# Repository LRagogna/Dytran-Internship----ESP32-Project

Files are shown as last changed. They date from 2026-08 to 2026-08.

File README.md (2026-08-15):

# Portable ESP32 Time-Study System

An end-to-end engineering project that turns production instructions into portable, operator-controlled time studies. The system combines a battery-powered ESP32 terminal, custom electronics and enclosure design, embedded firmware, and a Windows desktop application for creating, recording, reviewing, and exporting study data.

## Demo

[▶ Watch the ESP32 Time-Study System demo video](Pictures/esp32_time_study_demo.mp4)

The demo shows the completed handheld prototype running the on-device study workflow, including study selection, step navigation, and operator-controlled timing.

## Final prototype

The completed system packages the ESP32, display, physical controls, battery hardware, and interface electronics into a portable 3D-printed enclosure.

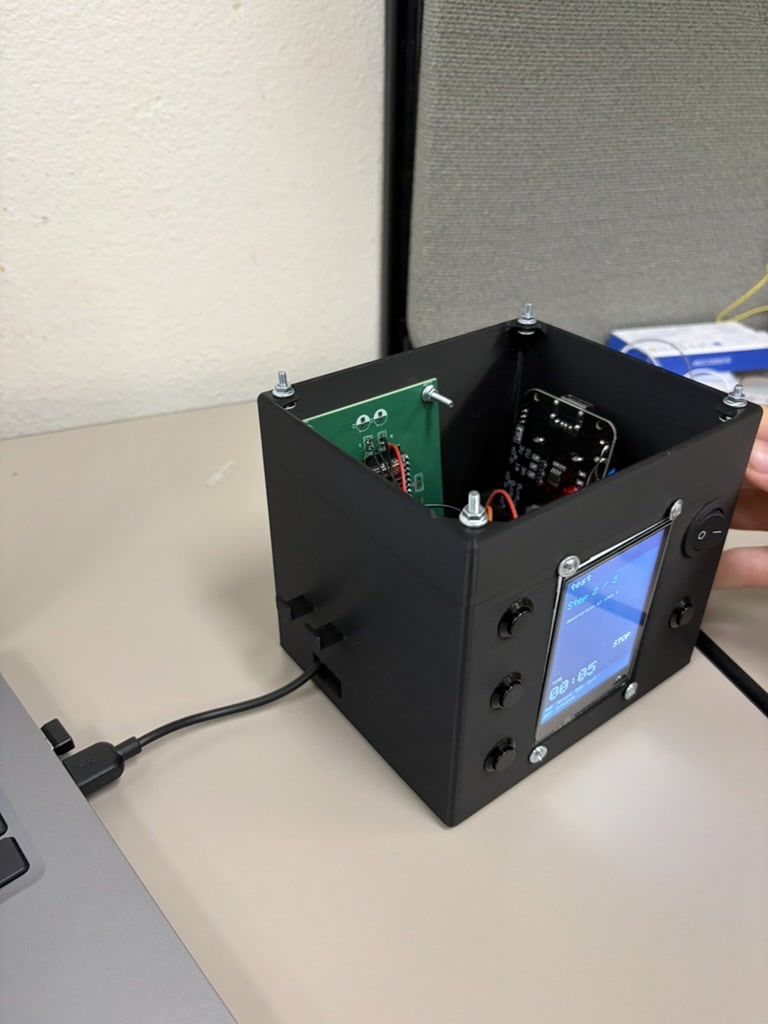
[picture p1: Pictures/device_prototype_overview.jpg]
Completed ESP32 time-study prototype


### On-device study selection

Stored studies can be selected directly from the handheld device before beginning a timing session.

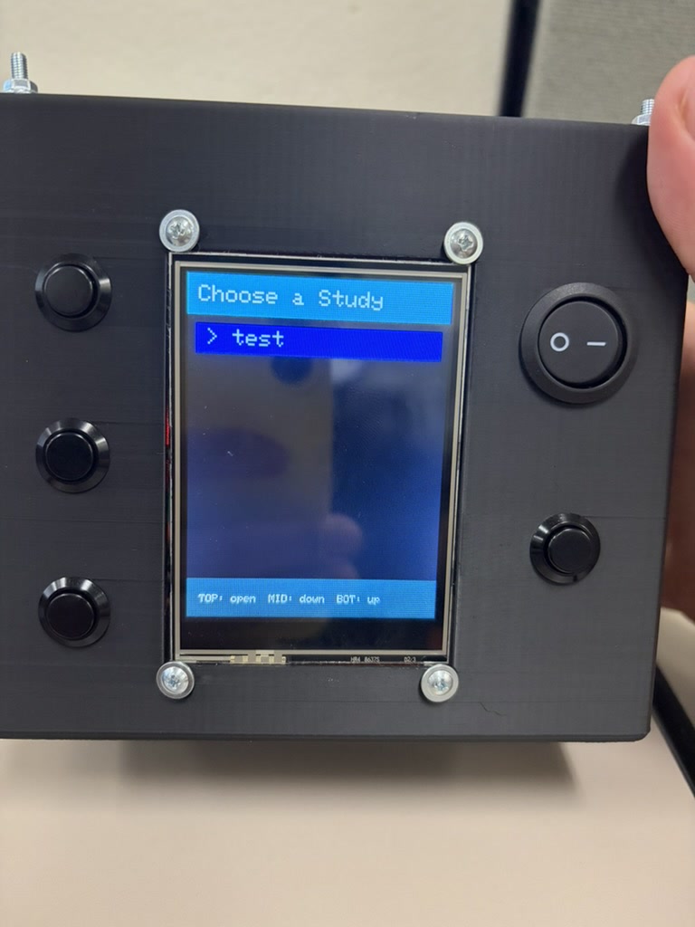
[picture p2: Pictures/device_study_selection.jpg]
ESP32 study selection interface


### Step timing workflow

The display presents the current operation while the physical controls allow the operator to record time and move between steps.

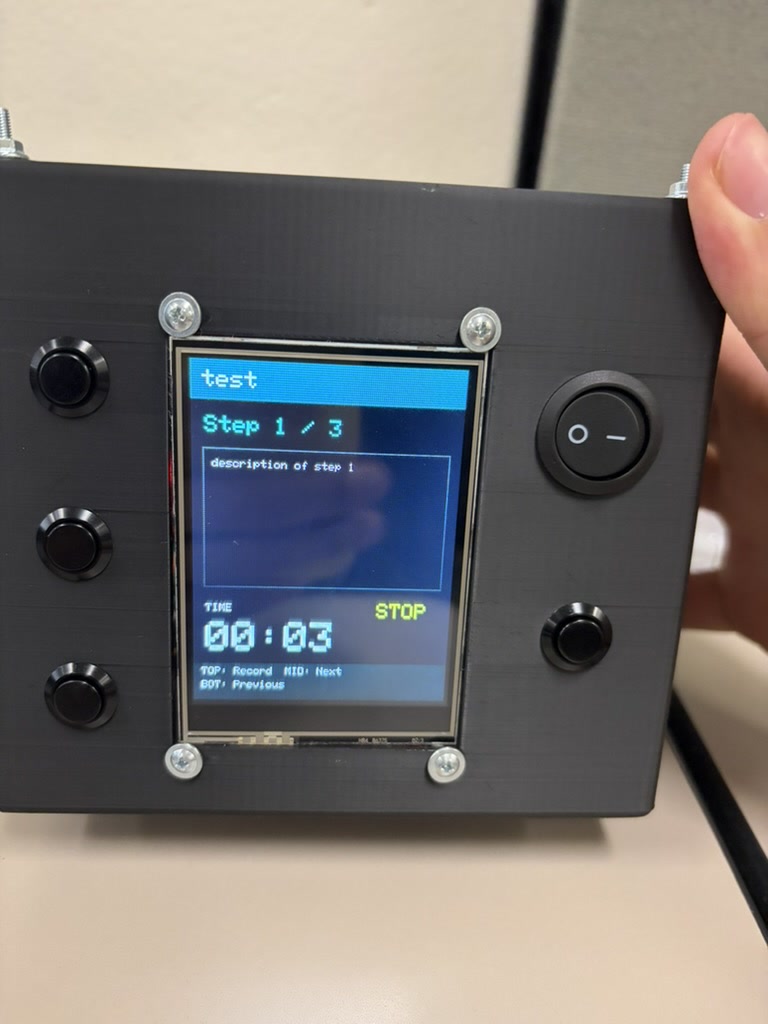
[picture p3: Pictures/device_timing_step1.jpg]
ESP32 timing interface step 1


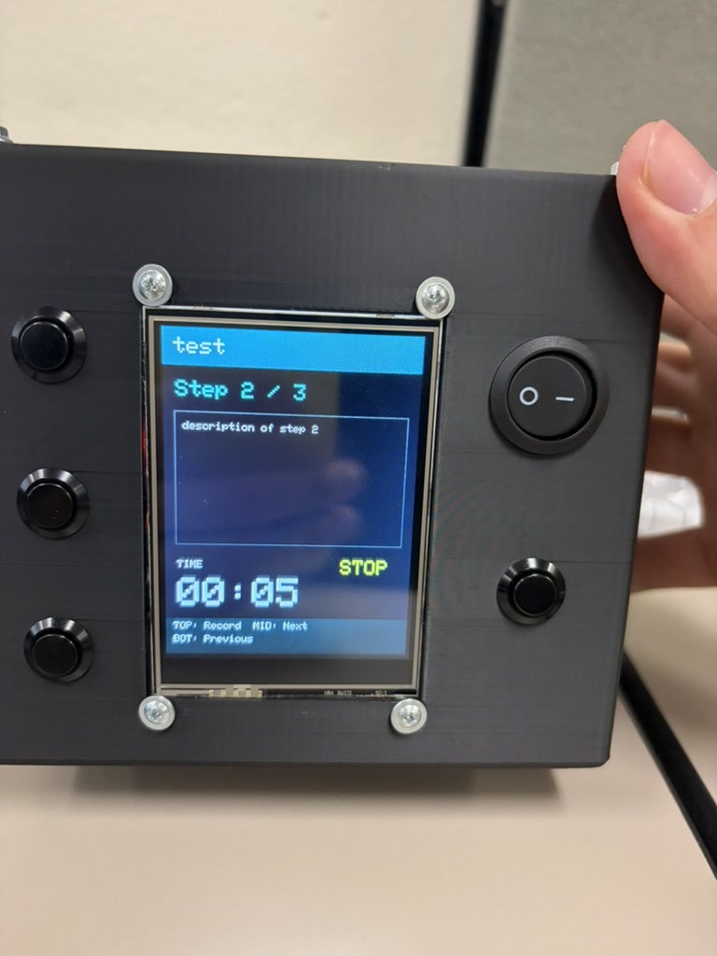
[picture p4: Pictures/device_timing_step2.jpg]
ESP32 timing interface step 2


### Internal electronics

The enclosure integrates the ESP32 development board, battery system, wiring, display interface, switches, and supporting electronics into a self-contained unit.

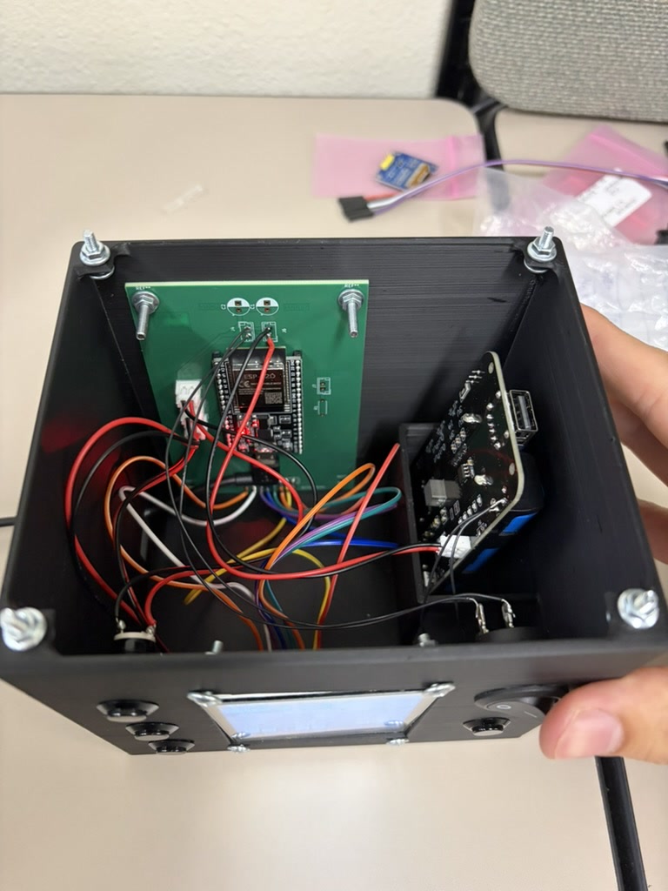
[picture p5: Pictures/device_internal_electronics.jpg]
ESP32 prototype internal electronics


## Engineering outcome

This project replaced a centralized, manually coordinated timing process with a portable workflow that can be used directly at the workstation. A single system now supports the full path from study creation to recorded results:

1. A user selects a sanitized Job Traveler or prepared study document.
2. The desktop application converts its operations into editable study steps.
3. The study is transferred to the ESP32 over USB.
4. An operator records elapsed time for each step from the handheld terminal.
5. Completed studies can be reviewed, downloaded as CSV files, or exported to Excel.

The result is a practical engineering tool that integrates mechanical design, electronics, embedded programming, desktop software, serial communication, and structured data export into one deployable system.

## Key accomplishments

- Designed and built a portable ESP32 operator terminal for decentralized time collection.
- Developed a custom 3D-printed enclosure in SolidWorks around the display, controls, battery system, and internal electronics.
- Created a three-button interface that allows operators to select studies, move between steps, and start or stop timing without a keyboard.
- Implemented local CSV storage so studies remain available directly on the ESP32.
- Defined a lightweight serial command protocol between the Windows application and the embedded device.
- Built a desktop application for study creation, file management, CSV preview, deletion, and Excel export.
- Added editable step previews so users can correct, reorder, remove, or add operations before transferring a study.
- Produced repeatable build configuration and end-user documentation for deployment and support.
- Developed the system for use across multiple manufacturing departments, demonstrating that the design could scale beyond a single workstation.

## System architecture

```mermaid
flowchart TD
    A[Sanitized study document] --> B[Windows Study Manager]
    B -->|USB serial| C[ESP32 terminal]
    C --> D[Local CSV storage]
    C --> E[Operator timing interface]
    D -->|USB serial| B
    B --> F[CSV download]
    B --> G[Excel workbook]
```

## Hardware

- ESP32-D DevKit development board
- 3.2-inch screen display
- Three momentary pushbuttons
- On/off power switch
- diymore dual-18650 battery holder and charging board
- 2.5 mm JST-EH connectors
- Custom interface PCB
- Custom SolidWorks enclosure and 3D-printed housing
- Wiring, fasteners, and supporting electronic components

The schematic includes provisions for decoupling capacitors and a buzzer. Those components were not installed on the final prototype after evaluation of the implemented design requirements.

## Engineering design visuals

### System schematic

The schematic documents the ESP32 connections, operator buttons, display interface, power input, switch, and optional buzzer circuit.

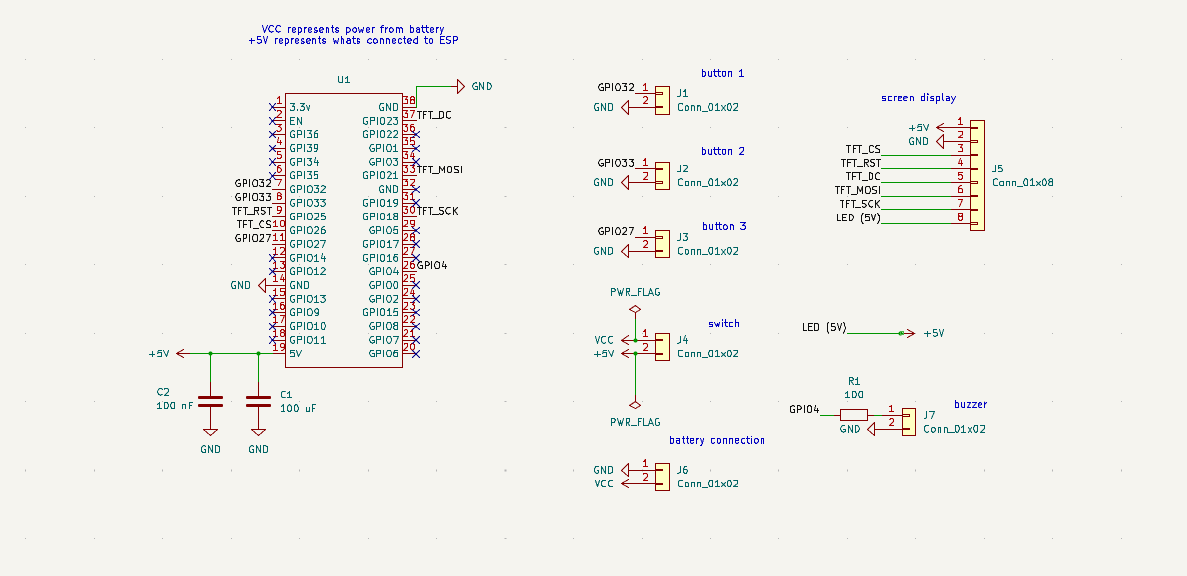
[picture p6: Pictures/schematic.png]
ESP32 time-study system schematic


### PCB layout

The custom PCB layout organizes the ESP32 headers, display and control connections, power components, and enclosure mounting points.

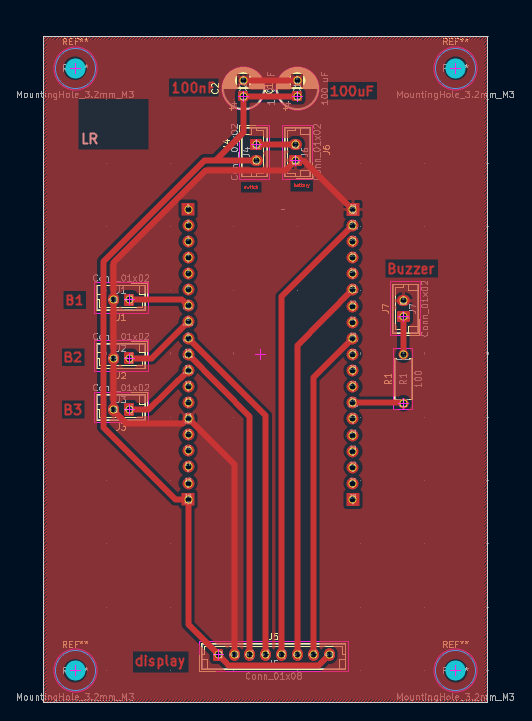
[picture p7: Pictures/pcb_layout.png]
Custom interface PCB layout


### PCB 3D view

The 3D board view was used to review component placement and mechanical integration before assembly.

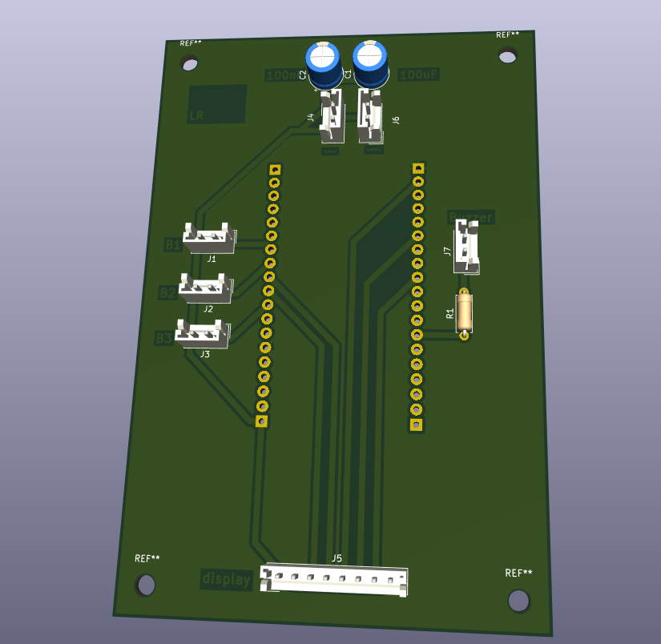
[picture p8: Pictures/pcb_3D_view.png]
Custom interface PCB 3D view


## Software

### ESP32 firmware

The firmware provides the on-device workflow and file-management layer. It:

- Displays stored studies and step information.
- Uses physical buttons for menu navigation and timing control.
- Accumulates elapsed time for each operation.
- Stores study definitions and results as CSV files.
- Responds to commands from the desktop application over a 115200-baud serial connection.

### Windows Study Manager

The desktop application is written in Python and uses a local HTML/CSS/JavaScript interface through `pywebview`. It provides four main workflows:

- **Home:** Detects the connected ESP32 and displays device status.
- **Create Study:** Parses a study document, previews its steps, and uploads the final study to the device.
- **Current Studies:** Lists stored CSV files and previews recorded results.
- **Export:** Combines selected studies into an Excel workbook with one worksheet per study.

## Data and serial workflow

The desktop application communicates with the ESP32 using simple text commands. The protocol supports:

- Creating a new study
- Adding numbered study steps
- Listing stored CSV files
- Retrieving a selected CSV file
- Deleting a study

Study results use a straightforward CSV structure:

```text
Step Number,Step Description,Time (mm:ss)
1,Example operation,00:00
2,Example operation,00:00
```

This format keeps the device implementation lightweight while making the results easy to inspect, archive, and analyze.

## Repository structure

```text
.
├── app.py                         # Desktop application and serial interface
├── jt_parser.py                   # Study-document step parser
├── esp32_reader.py                # Standalone ESP32 communication utility
├── flashMe/
│   └── flashMe.ino                # ESP32 firmware
├── web/
│   └── index.html                 # Desktop application interface
├── ESP32 Study Manager.spec       # PyInstaller build configuration
├── build.bat                      # Windows build helper
├── requirements.txt               # Python dependencies
├── Pictures/                      # Sanitized project images and demo video
├── Hardware Info.docx             # Hardware operation reference
├── Project Materials.docx         # Project bill of materials
└── User Guide - Sensitive Info. Removed.docx
                                     # Sanitized software user guide
```

## Installation

### Requirements

- Windows computer
- Python 3.10 or newer
- USB data cable
- Programmed ESP32 terminal
- CP210x or CH340 USB-to-serial driver when required by the connected board

### Set up the desktop application

```bash
git clone https://github.com/LRagogna/Dytran-Internship----ESP32-Project.git
cd Dytran-Internship----ESP32-Project
python -m venv .venv
.venv\Scripts\activate
pip install -r requirements.txt
python app.py
```

### Build the Windows executable

Install PyInstaller if it is not already available, then run:

```bat
build.bat
```

The included `.spec` file packages the Python application and web interface into the Windows build.

## Typical use

1. Connect the ESP32 terminal to the computer with a USB data cable.
2. Start the ESP32 Study Manager.
3. Confirm that the device appears as connected.
4. Open **Create Study** and select a sanitized input document.
5. Review and edit the parsed operations.
6. Enter non-sensitive study identifiers and transfer the study to the ESP32.
7. Disconnect the portable terminal and record each operation at the workstation.
8. Reconnect the terminal to review, download, or export the completed study.

## Engineering disciplines demonstrated

- Embedded C/C++ development
- Python desktop application development
- HTML, CSS, and JavaScript user-interface design
- USB serial communication and protocol design
- PCB schematic capture and layout
- Power-system and battery integration
- SolidWorks enclosure design
- 3D printing and mechanical assembly
- CSV and Excel data processing
- System integration, troubleshooting, and technical documentation

## Author

Leonardo Ragogna

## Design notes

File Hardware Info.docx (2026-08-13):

Hardware Info

Using the ESP32 time-study device

The device stores studies created from the PC app and records how long each step takes. Everything is done with the three buttons and the on-screen display.

Power

Turn it on

The battery sits on side of the box and charges with a USB-A charger.

Before use, press the boot button — located just below the on/off switch on the right side of the box — to switch the battery on.

Buttons

Button | On the study list | During a study
Top | Open the highlighted study | Start / stop recording the current step
Middle | Move selection down | Next step
Bottom | Move selection up | Previous step (from Step 1, back to the list)

Using it

1. Power on. The Choose a Study list appears. If it’s empty, create a study from the PC app first.

2. Use Middle / Bottom to highlight a study, then Top to open it.

3. On a step, press Top to start timing (the screen shows REC in green). Press Top again to stop and save. Recorded time adds up if you time a step more than once.

4. Move between steps with Middle / Bottom when not recording. From Step 1, Bottom returns to the study list.

The screen shows the study name, Step X / N, the step description, the running time, and REC / STOP status. You can’t change steps while recording — stop first.

Debugging

If the boot button does not work, try turning the switch on and then plugging the USB cord into computer. Then unplug, and screen should stay on.

ESP32 Study Manager – Hardware Info Page 1 UNRESTRICTED

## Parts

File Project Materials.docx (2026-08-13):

Dytran ESP32 Project Materials

Materials used in the portable ESP32 operator-terminal build

# Materials used

- ESP32-D DevKit board — Microcontroller development board used as the main controller.
- diymore 18650 battery holder and charging board — Double Li-ion V8 battery shield with Micro-USB power-bank outputs (5 V/3 A and 3 V/1 A); holds two 18650 cells. Amazon product page (https://www.amazon.com/Diymore-Lithium-Battery-Charging-Arduino/dp/B07SZKNST4)
- 2.5 mm JST-EH connectors — Wire-to-board connectors used for internal electrical connections.
- 3.2-inch screen display — Display used for the operator interface.
- Standard momentary pushbuttons — Amazon-sourced controls used for operator input.
- Standard on/off switch — Amazon-sourced switch used to control system power.

# Schematic and assembled-board note

Design clarification: The schematic calls for decoupling capacitors throughout the circuit and includes a buzzer. These components were omitted from the assembled board because they were deemed unnecessary for the final implementation.

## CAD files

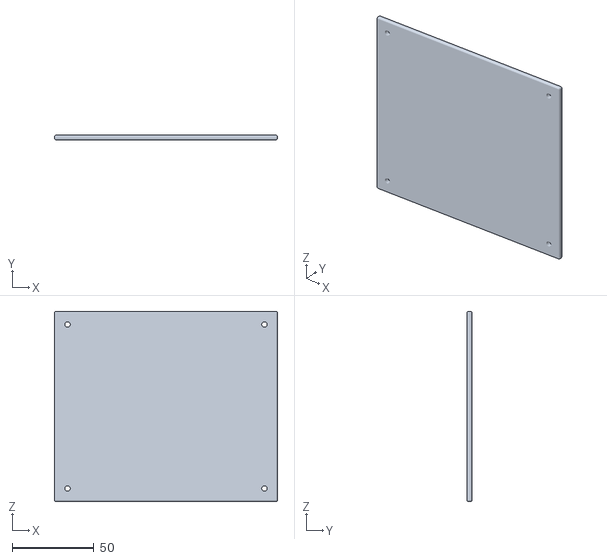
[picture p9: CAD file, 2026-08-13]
Solidworks/lid.STL
136.0 x 3.00 x 116.0

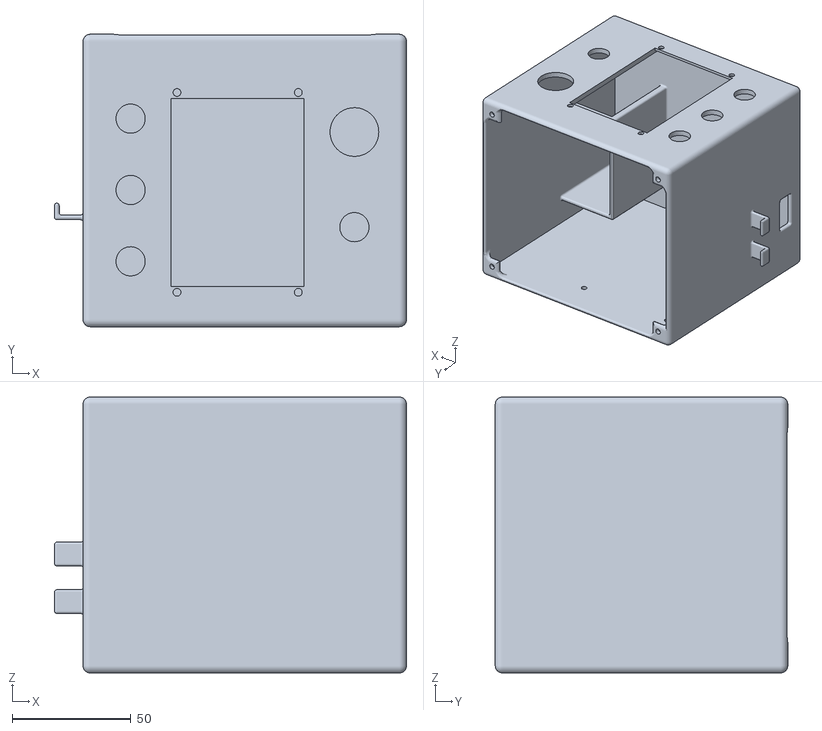
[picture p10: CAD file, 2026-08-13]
Solidworks/base.STL
148.0 x 123.0 x 116.0

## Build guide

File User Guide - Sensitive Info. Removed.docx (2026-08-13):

User Guide

Using the ESP32 Study Manager

The ESP32 Study Manager turns a Job Traveler PDF into a time study stored on your ESP32 device, lets you review recorded studies, and exports them to Excel. This guide walks through the four tabs — Home, Create Study, Current Studies, and Export — in the order you’ll normally use them.

Before you start

Connect the ESP32 to your computer with a USB cable before opening the app. If Windows doesn’t recognize the device, install the CP210x driver first (see the Driver Setup Guide).

1. Home — check your connection

The Home tab confirms the app can see your device. A green dot reading Connected — COMx means you’re ready to go. The Device Information panel shows the port, USB device, manufacturer, how many studies are stored, and the baud rate. If you plug in the ESP32 after opening the app, click Refresh Device.

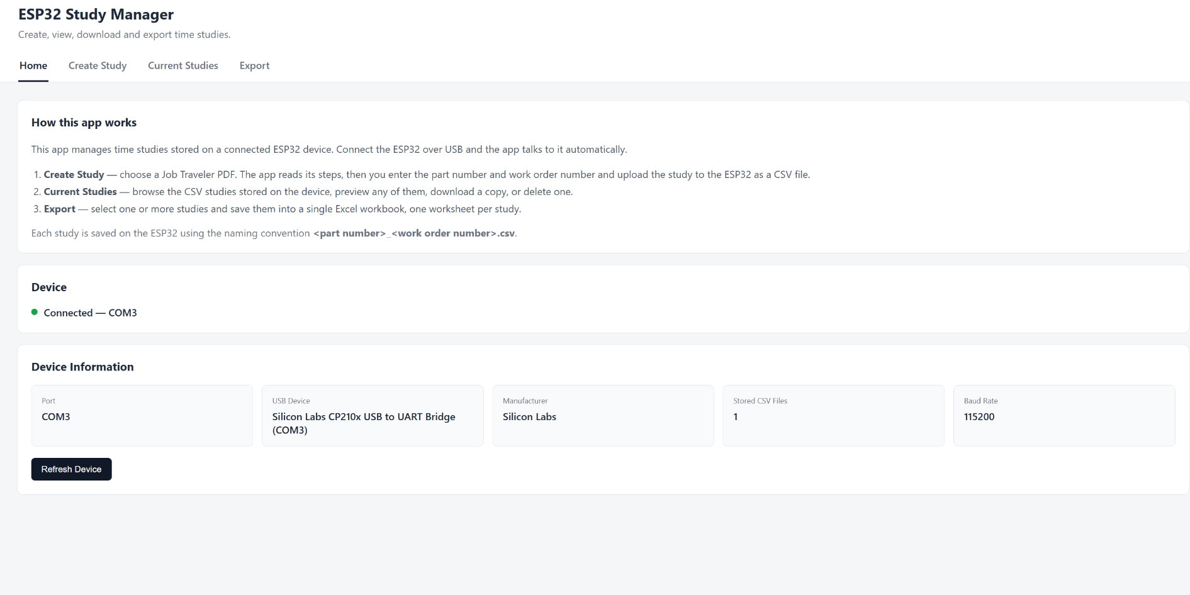
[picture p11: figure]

The Home tab, showing a connected device and its details.

2. Create Study — build a study from a PDF

Open the Create Study tab and click Choose JT PDF to select a Job Traveler PDF. The app reads the steps directly from the document.

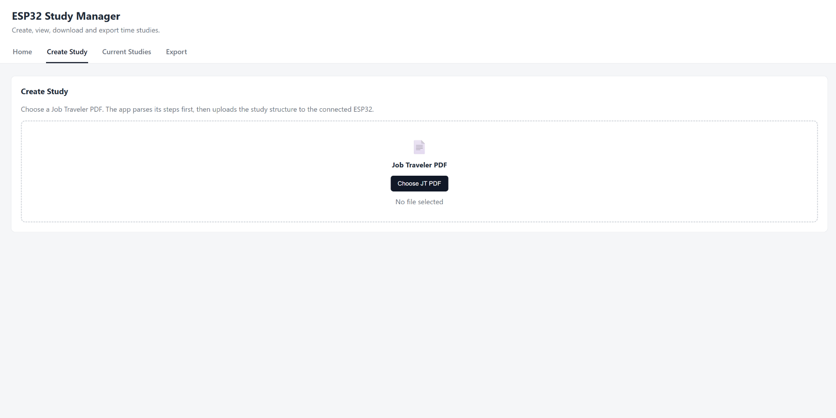
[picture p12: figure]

The Create Study tab before a PDF is chosen.

Once the PDF is parsed, fill in the required Part number and Work order number. Together these name the study on the device as <part>_<WO>.csv. You can optionally set a Custom name to override that. Review the parsed steps below: click any description to edit it, use the ↑ / ↓ arrows to reorder, ✕ to remove a step, or + Add Step to insert one. When it all looks right, click Create Study on ESP32.

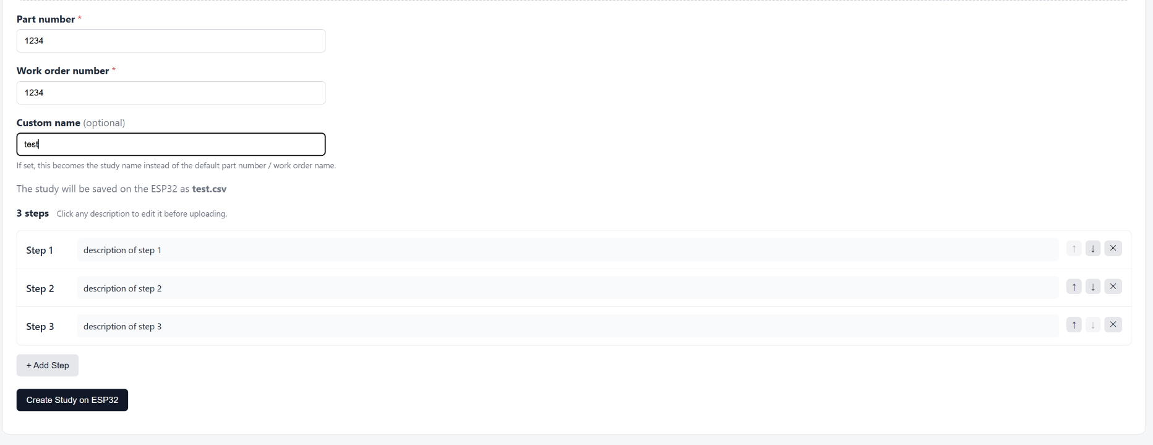
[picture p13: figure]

Example JT parsed.

3. Current Studies — review and manage

The Current Studies tab lists every study stored on the ESP32. Select one to preview its steps alongside the recorded times (mm:ss). Use Download CSV to save a copy to your computer. The Delete File panel removes a study from the device permanently — it asks for two confirmations and cannot be undone.

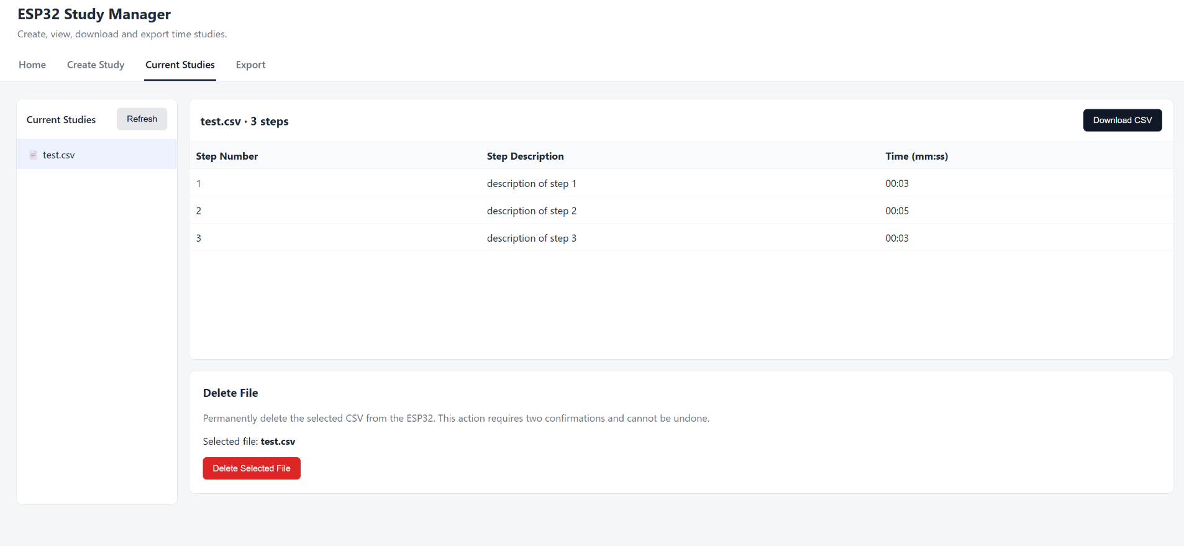
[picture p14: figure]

Sample CSV files show up in this section.

4. Export — save studies to Excel

The Export tab turns studies into a single Excel workbook. Check the studies you want (or use Select all), click Export Excel, and choose where to save. Each study becomes its own worksheet, with step numbers, descriptions, and times.

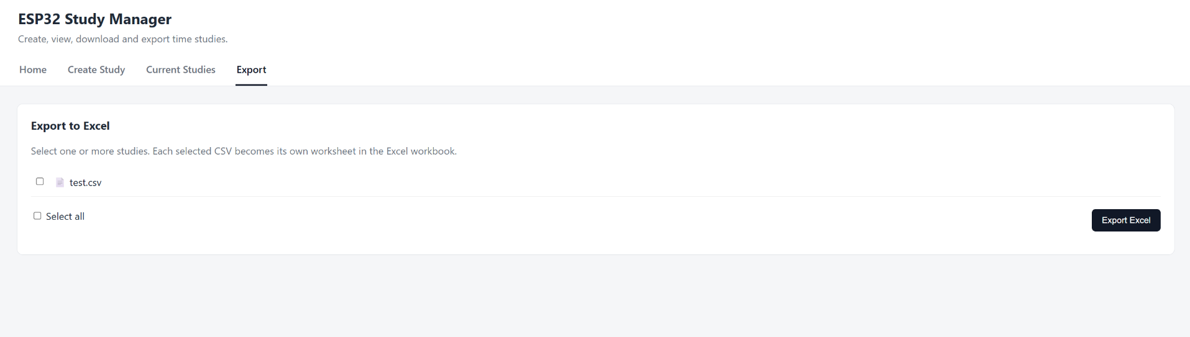
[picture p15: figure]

The Export tab, ready to save selected studies to Excel.

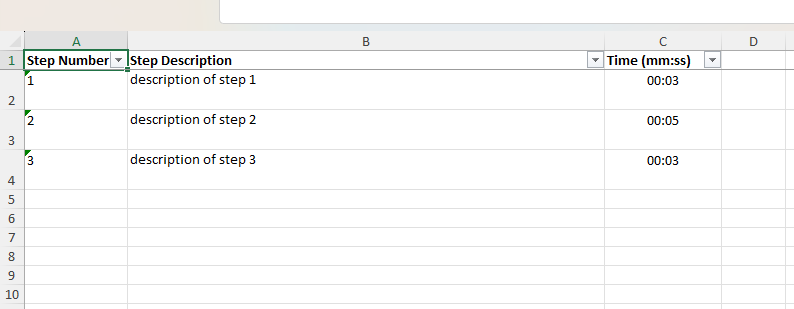
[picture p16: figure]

Excel files have information stored in the following format.

Tip

Because every study is named by part and work order number, exported workbooks are easy to match back to the job they came from.

ESP32 Study Manager – User Guide Page 1 of 2 UNRESTRICTED

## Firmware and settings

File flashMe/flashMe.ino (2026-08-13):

#include <LittleFS.h>
#include <SPI.h>
#include <Adafruit_GFX.h>
#include <Adafruit_ILI9341.h>

// ======================================================
// PCB BUTTON PINS
// ======================================================

const int TOP_PIN = 32;   // B1
const int MID_PIN = 33;   // B2
const int BOT_PIN = 27;   // B3


// ======================================================
// PCB TFT PINS
// J5:
// 1 = +5V
// 2 = GND
// 3 = CS
// 4 = RST
// 5 = DC
// 6 = MOSI
// 7 = SCK
// 8 = LED +5V
// ======================================================

const int TFT_CS   = 26;
const int TFT_RST  = 25;
const int TFT_DC   = 23;
const int TFT_MOSI = 21;
const int TFT_SCK  = 18;


// ======================================================
// TFT
// ======================================================

Adafruit_ILI9341 tft =
  Adafruit_ILI9341(
    &SPI,
    TFT_DC,
    TFT_CS,
    TFT_RST
  );


// ======================================================
// STUDY STATE
// ======================================================

String currentStudy = "";

int currentStepIndex = 0;

bool timerRunning = false;

unsigned long timerStartMs = 0;

bool homeMenuActive = true;

int selectedStudyIndex = 0;


// ======================================================
// BUTTON DEBOUNCE
// ======================================================

bool lastTopState = HIGH;
bool lastMidState = HIGH;
bool lastBotState = HIGH;

unsigned long lastTopPress = 0;
unsigned long lastMidPress = 0;
unsigned long lastBotPress = 0;

const unsigned long DEBOUNCE_MS = 200;


// ======================================================
// TFT REFRESH
// ======================================================

unsigned long lastScreenUpdate = 0;

const unsigned long SCREEN_UPDATE_MS = 250;


// ======================================================
// HELPERS
// ======================================================

String normalizeFilename(String filename) {
  filename.trim();

  if (!filename.endsWith(".csv")) {
    filename += ".csv";
  }

  if (!filename.startsWith("/")) {
    filename = "/" + filename;
  }

  return filename;
}


String displayFilename(String filename) {
  if (filename.startsWith("/")) {
    filename =
      filename.substring(1);
  }

  if (filename.endsWith(".csv")) {
    filename =
      filename.substring(
        0,
        filename.length() - 4
      );
  }

  return filename;
}


String csvEscape(String value) {
  value.replace("\r", " ");
  value.replace("\n", " ");

  bool needsQuotes =
    value.indexOf(',') >= 0 ||
    value.indexOf('"') >= 0;

  value.replace("\"", "\"\"");

  if (needsQuotes) {
    value =
      "\"" + value + "\"";
  }

  return value;
}


// ======================================================
// HOME MENU HELPERS
// ======================================================

bool isStudyFile(String filename) {
  return
    filename.endsWith(".csv") &&
    filename != "/temp_study.csv" &&
    filename != "temp_study.csv";
}


int getStudyCount() {
  File root = LittleFS.open("/");

  if (!root) return 0;

  int count = 0;
  File file = root.openNextFile();

  while (file) {
    if (!file.isDirectory() && isStudyFile(String(file.name()))) count++;
    file.close();
    file = root.openNextFile();
  }

  root.close();
  return count;
}


String getStudyFilename(int targetIndex) {
  File root = LittleFS.open("/");

  if (!root) return "";

  int studyIndex = 0;
  File file = root.openNextFile();

  while (file) {
    if (!file.isDirectory()) {
      String name = String(file.name());

      if (isStudyFile(name)) {
        if (studyIndex == targetIndex) {
          file.close();
          root.close();
          return normalizeFilename(name);
        }

        studyIndex++;
      }
    }

    file.close();
    file = root.openNextFile();
  }

  root.close();
  return "";
}


void drawHomeMenu() {
  tft.fillScreen(ILI9341_BLACK);
  tft.fillRect(0, 0, 240, 36, ILI9341_DARKCYAN);
  tft.setTextColor(ILI9341_WHITE);
  tft.setTextSize(2);
  tft.setCursor(10, 10);
  tft.print("Choose a Study");

  int studyCount = getStudyCount();

  if (studyCount <= 0) {
    selectedStudyIndex = 0;
    tft.setTextColor(ILI9341_YELLOW);
    tft.setCursor(18, 72);
    tft.print("No studies found");
    tft.setTextSize(1);
    tft.setTextColor(ILI9341_WHITE);
    tft.setCursor(18, 108);
    tft.print("Create one through USB first.");
    return;
  }

  if (selectedStudyIndex >= studyCount) selectedStudyIndex = studyCount - 1;

  const int visibleRows = 7;
  int firstVisible = selectedStudyIndex - (visibleRows / 2);

  if (firstVisible < 0) firstVisible = 0;
  if (firstVisible > studyCount - visibleRows) {
    firstVisible = max(0, studyCount - visibleRows);
  }

  for (int row = 0; row < visibleRows; row++) {
    int studyIndex = firstVisible + row;
    if (studyIndex >= studyCount) break;

    int y = 48 + row * 30;
    bool selected = studyIndex == selectedStudyIndex;

    if (selected) tft.fillRect(8, y - 4, 224, 26, ILI9341_BLUE);

    String title = displayFilename(getStudyFilename(studyIndex));
    if (title.length() > 15) title = title.substring(0, 15);

    tft.setTextColor(selected ? ILI9341_WHITE : ILI9341_LIGHTGREY);
    tft.setTextSize(2);
    tft.setCursor(16, y);
    tft.print(selected ? "> " : "  ");
    tft.print(title);
  }

  tft.fillRect(0, 282, 240, 38, ILI9341_DARKCYAN);
  tft.setTextSize(1);
  tft.setTextColor(ILI9341_WHITE, ILI9341_DARKCYAN);
  tft.setCursor(12, 298);
  tft.print("TOP: open  MID: down  BOT: up");
}


// ======================================================
// TIME HELPERS
// ======================================================

unsigned long parseTimeToSeconds(
  String timeValue
) {
  timeValue.trim();

  if (timeValue.length() == 0) {
    return 0;
  }

  int colon =
    timeValue.indexOf(':');

  if (colon < 0) {
    return 0;
  }

  unsigned long minutes =
    timeValue
      .substring(0, colon)
      .toInt();

  unsigned long seconds =
    timeValue
      .substring(colon + 1)
      .toInt();

  return
    minutes * 60 +
    seconds;
}


String formatSeconds(
  unsigned long totalSeconds
) {
  unsigned long minutes =
    totalSeconds / 60;

  unsigned long seconds =
    totalSeconds % 60;

  char buffer[16];

  snprintf(
    buffer,
    sizeof(buffer),
    "%02lu:%02lu",
    minutes,
    seconds
  );

  return String(buffer);
}


// ======================================================
// SIMPLE CSV FIELD PARSER
//
// Handles:
// 1,"description, with comma",00:30
// ======================================================

String getCSVField(
  String line,
  int targetField
) {
  bool inQuotes = false;

  int fieldIndex = 0;
  int startIndex = 0;

  for (
    int i = 0;
    i <= line.length();
    i++
  ) {
    char c =
      i < line.length()
      ? line[i]
      : ',';

    if (c == '"') {
      if (
        inQuotes &&
        i + 1 < line.length() &&
        line[i + 1] == '"'
      ) {
        i++;
      }
      else {
        inQuotes = !inQuotes;
      }
    }

    if (
      c == ',' &&
      !inQuotes
    ) {
      if (
        fieldIndex ==
        targetField
      ) {
        String field =
          line.substring(
            startIndex,
            i
          );

        field.trim();

        if (
          field.startsWith("\"") &&
          field.endsWith("\"") &&
          field.length() >= 2
        ) {
          field =
            field.substring(
              1,
              field.length() - 1
            );

          field.replace(
            "\"\"",
            "\""
          );
        }

        return field;
      }

      fieldIndex++;

      startIndex =
        i + 1;
    }
  }

  return "";
}


// ======================================================
// STEP COUNT
// ======================================================

int getStepCount() {
  if (
    currentStudy.length() == 0
  ) {
    return 0;
  }

  File file =
    LittleFS.open(
      currentStudy,
      "r"
    );

  if (!file) {
    return 0;
  }

  int count = 0;

  bool firstLine = true;

  while (file.available()) {
    String line =
      file.readStringUntil('\n');

    line.trim();

    if (
      firstLine
    ) {
      firstLine = false;
      continue;
    }

    if (
      line.length() > 0
    ) {
      count++;
    }
  }

  file.close();

  return count;
}


// ======================================================
// GET CURRENT STEP DATA
// ======================================================

bool getCurrentStepData(
  String &stepNumber,
  String &description,
  String &storedTime
) {
  if (
    currentStudy.length() == 0
  ) {
    return false;
  }

  File file =
    LittleFS.open(
      currentStudy,
      "r"
    );

  if (!file) {
    return false;
  }

  int dataIndex = -1;

  while (file.available()) {
    String line =
      file.readStringUntil('\n');

    line.replace(
      "\r",
      ""
    );

    if (
      dataIndex == -1
    ) {
      dataIndex++;
      continue;
    }

    if (
      dataIndex ==
      currentStepIndex
    ) {
      stepNumber =
        getCSVField(
          line,
          0
        );

      description =
        getCSVField(
          line,
          1
        );

      storedTime =
        getCSVField(
          line,
          2
        );

      file.close();

      return true;
    }

    dataIndex++;
  }

  file.close();

  return false;
}


// ======================================================
// CURRENT DISPLAY TIME
//
// Existing stored time + currently running segment
// ======================================================

String getCurrentDisplayTime() {
  String stepNumber;
  String description;
  String storedTime;

  if (
    !getCurrentStepData(
      stepNumber,
      description,
      storedTime
    )
  ) {
    return "00:00";
  }

  unsigned long totalSeconds =
    parseTimeToSeconds(
      storedTime
    );

  if (timerRunning) {
    unsigned long elapsedMs =
      millis() -
      timerStartMs;

    totalSeconds +=
      elapsedMs / 1000;
  }

  return
    formatSeconds(
      totalSeconds
    );
}


// ======================================================
// TFT TEXT WRAPPING
// ======================================================

void drawWrappedText(
  String text,
  int x,
  int y,
  int maxWidth,
  int maxLines,
  uint16_t color,
  uint8_t textSize
) {
  tft.setTextColor(
    color,
    ILI9341_BLACK
  );

  tft.setTextSize(
    textSize
  );

  int charWidth =
    6 * textSize;

  int charsPerLine =
    maxWidth /
    charWidth;

  if (
    charsPerLine < 1
  ) {
    charsPerLine = 1;
  }

  String remaining =
    text;

  for (
    int line = 0;
    line < maxLines &&
    remaining.length() > 0;
    line++
  ) {
    int breakPos =
      min(
        charsPerLine,
        (int)remaining.length()
      );

    if (
      breakPos <
      remaining.length()
    ) {
      int space =
        remaining.lastIndexOf(
          ' ',
          breakPos
        );

      if (space > 0) {
        breakPos =
          space;
      }
    }

    String piece =
      remaining.substring(
        0,
        breakPos
      );

    piece.trim();

    tft.setCursor(
      x,
      y +
      line *
      (8 * textSize)
    );

    tft.print(
      piece
    );

    remaining =
      remaining.substring(
        breakPos
      );

    remaining.trim();
  }
}


// ======================================================
// TFT SCREEN
// ======================================================

void drawScreen() {
  tft.fillScreen(
    ILI9341_BLACK
  );

  // ----------------------------------
  // No study selected
  // ----------------------------------

  if (
    currentStudy.length() == 0
  ) {
    tft.setTextColor(
      ILI9341_WHITE
    );

    tft.setTextSize(2);

    tft.setCursor(
      20,
      40
    );

    tft.println(
      "No Study Selected"
    );

    tft.setTextSize(1);

    tft.setCursor(
      20,
      80
    );

    tft.println(
      "Use SELECT through USB"
    );

    return;
  }


  String stepNumber;
  String description;
  String storedTime;

  if (
    !getCurrentStepData(
      stepNumber,
      description,
      storedTime
    )
  ) {
    tft.setTextColor(
      ILI9341_WHITE
    );

    tft.setTextSize(2);

    tft.setCursor(
      20,
      40
    );

    tft.println(
      "No Steps"
    );

    return;
  }


  int stepCount =
    getStepCount();


  // ==================================================
  // HEADER
  // ==================================================

  tft.fillRect(
    0,
    0,
    240,
    34,
    ILI9341_DARKCYAN
  );

  tft.setTextColor(
    ILI9341_WHITE
  );

  tft.setTextSize(2);

  tft.setCursor(
    10,
    9
  );

  String title =
    displayFilename(
      currentStudy
    );

  if (
    title.length() > 17
  ) {
    title =
      title.substring(
        0,
        17
      );
  }

  tft.print(
    title
  );


  // ==================================================
  // STEP NUMBER
  // ==================================================

  tft.setTextColor(
    ILI9341_CYAN
  );

  tft.setTextSize(2);

  tft.setCursor(
    12,
    48
  );

  tft.print(
    "Step "
  );

  tft.print(
    currentStepIndex + 1
  );

  tft.print(
    " / "
  );

  tft.println(
    stepCount
  );


  // ==================================================
  // DESCRIPTION
  // ==================================================

  tft.drawRect(
    10,
    76,
    220,
    130,
    ILI9341_DARKGREY
  );

  drawWrappedText(
    description,
    18,
    86,
    204,
    13,
    ILI9341_WHITE,
    1
  );


  // ==================================================
  // TIME
  // ==================================================

  tft.setTextColor(
    ILI9341_WHITE
  );

  tft.setTextSize(1);

  tft.setCursor(
    12,
    222
  );

  tft.print(
    "TIME"
  );


  tft.setTextSize(4);

  tft.setCursor(
    12,
    240
  );

  if (timerRunning) {
    tft.setTextColor(
      ILI9341_GREEN
    );
  }
  else {
    tft.setTextColor(
      ILI9341_WHITE
    );
  }

  tft.print(
    getCurrentDisplayTime()
  );


  // ==================================================
  // STATUS
  // ==================================================

  tft.setTextSize(2);

  if (timerRunning) {
    tft.setTextColor(
      ILI9341_GREEN
    );

    tft.setCursor(
      170,
      220
    );

    tft.print(
      "REC"
    );
  }

  else {
    tft.setTextColor(
      ILI9341_YELLOW
    );

    tft.setCursor(
      170,
      220
    );

    tft.print(
      "STOP"
    );
  }


  // ==================================================
  // BUTTON HELP
  // ==================================================

  tft.fillRect(0, 282, 240, 38, ILI9341_DARKCYAN);
  tft.setTextSize(1);
  tft.setTextColor(ILI9341_WHITE, ILI9341_DARKCYAN);
  tft.setCursor(8, 286);
  tft.print("TOP: Record  MID: Next");
  tft.setCursor(8, 300);
  tft.print("BOT: Previous");
}


// ======================================================
// UPDATE ONLY TIME AREA
//
// Avoids full-screen flashing while recording.
// ======================================================

void updateRunningTimeDisplay() {
  if (!timerRunning) {
    return;
  }

  if (
    millis() -
    lastScreenUpdate <
    SCREEN_UPDATE_MS
  ) {
    return;
  }

  lastScreenUpdate =
    millis();

  tft.fillRect(
    10,
    237,
    150,
    45,
    ILI9341_BLACK
  );

  tft.setTextColor(
    ILI9341_GREEN,
    ILI9341_BLACK
  );

  tft.setTextSize(4);

  tft.setCursor(
    12,
    240
  );

  tft.print(
    getCurrentDisplayTime()
  );
}


void openSelectedStudy() {
  int studyCount = getStudyCount();

  if (studyCount <= 0) {
    Serial.println("ERROR:NO_STUDIES");
    drawHomeMenu();
    return;
  }

  String filename = getStudyFilename(selectedStudyIndex);

  if (filename.length() == 0) {
    Serial.println("ERROR:FILE_NOT_FOUND");
    drawHomeMenu();
    return;
  }

  currentStudy = filename;
  currentStepIndex = 0;
  timerRunning = false;
  homeMenuActive = false;

  Serial.print("OK:SELECTED:");
  Serial.println(currentStudy);
  drawScreen();
}


// ======================================================
// ADD TIME TO CURRENT STEP
// ======================================================

bool addTimeToCurrentStep(
  unsigned long newElapsedMs
) {
  if (
    currentStudy.length() == 0
  ) {
    Serial.println(
      "ERROR:NO_STUDY_SELECTED"
    );

    return false;
  }

  File source =
    LittleFS.open(
      currentStudy,
      "r"
    );

  if (!source) {
    Serial.println(
      "ERROR:OPEN_FAILED"
    );

    return false;
  }

  String tempFile =
    "/temp_study.csv";

  File destination =
    LittleFS.open(
      tempFile,
      "w"
    );

  if (!destination) {
    source.close();

    Serial.println(
      "ERROR:TEMP_FILE_FAILED"
    );

    return false;
  }

  int dataRow = -1;

  String finalTime = "";

  while (
    source.available()
  ) {
    String line =
      source.readStringUntil(
        '\n'
      );

    line.replace(
      "\r",
      ""
    );


    // Header

    if (
      dataRow == -1
    ) {
      destination.println(
        line
      );

      dataRow++;

      continue;
    }


    // Current row

    if (
      dataRow ==
      currentStepIndex
    ) {
      String existingTime =
        getCSVField(
          line,
          2
        );

      unsigned long existingSeconds =
        parseTimeToSeconds(
          existingTime
        );


      unsigned long addedSeconds =
        (
          newElapsedMs +
          500
        ) /
        1000;


      unsigned long totalSeconds =
        existingSeconds +
        addedSeconds;


      finalTime =
        formatSeconds(
          totalSeconds
        );


      String stepNumber =
        getCSVField(
          line,
          0
        );

      String description =
        getCSVField(
          line,
          1
        );


      destination.print(
        stepNumber
      );

      destination.print(
        ","
      );

      destination.print(
        csvEscape(
          description
        )
      );

      destination.print(
        ","
      );

      destination.println(
        finalTime
      );
    }

    else {
      destination.println(
        line
      );
    }

    dataRow++;
  }

  source.close();

  destination.close();


  LittleFS.remove(
    currentStudy
  );


  if (
    !LittleFS.rename(
      tempFile,
      currentStudy
    )
  ) {
    Serial.println(
      "ERROR:RENAME_FAILED"
    );

    return false;
  }


  Serial.print(
    "TOTAL_TIME:"
  );

  Serial.println(
    finalTime
  );


  return true;
}


// ======================================================
// TOP BUTTON
// START / STOP
// ======================================================
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
void loop() {
  checkButtons();


  updateRunningTimeDisplay();


  if (
    !Serial.available()
  ) {
    return;
  }


  String input =
    Serial.readStringUntil(
      '\n'
    );


  input.trim();


  if (
    input.length() == 0
  ) {
    return;
  }


  // ==================================================
  // SIMULATED BUTTONS
  // ==================================================

  if (
    input == "TOP"
  ) {
    handleTop();
  }


  else if (
    input == "MID"
  ) {
    handleMid();
  }


  else if (
    input == "BOT"
  ) {
    handleBot();
  }


  // ==================================================
  // CREATE STUDY
  // ==================================================

  else if (
    input.startsWith(
      "NEWSTUDY "
    )
  ) {
    createStudy(
      input.substring(
        9
      )
    );
  }


  // ==================================================
  // SELECT STUDY
  // ==================================================

  else if (
    input.startsWith(
      "SELECT "
    )
  ) {
    selectStudy(
      input.substring(
        7
      )
    );
  }


  // ==================================================
  // CURRENT
  // ==================================================

  else if (
    input == "CURRENT"
  ) {
    showCurrentStudy();
  }


  // ==================================================
  // HOME MENU
  // ==================================================

  else if (input == "HOME") {
    if (timerRunning) {
      Serial.println("ERROR:TIMER_RUNNING");
    }
    else {
      homeMenuActive = true;
      selectedStudyIndex = 0;
      Serial.println("OK:HOME");
      drawHomeMenu();
    }
  }


  // ==================================================
  // ADD JT STEP
  // ==================================================

  else if (
    input.startsWith(
      "STEP "
    )
  ) {
    addStep(
      input.substring(
        5
      )
    );
  }


  // ==================================================
  // LIST
  // ==================================================

  else if (
    input == "LIST"
  ) {
    listCSVs();
  }


  // ==================================================
  // GET
  // ==================================================

  else if (
    input.startsWith(
      "GET "
    )
  ) {
    sendCSV(
      input.substring(
        4
      )
    );
  }


  // ==================================================
  // DELETE
  // ==================================================

  else if (
    input.startsWith(
      "DELETE "
    )
  ) {
    deleteCSV(
      input.substring(
        7
      )
    );
  }


  // ==================================================
  // PING
  // ==================================================

  else if (
    input == "PING"
  ) {
    Serial.println(
      "ESP32_STUDY_MANAGER"
    );
  }


  else {
    Serial.println(
      "ERROR:UNKNOWN_COMMAND"
    );
  }
}

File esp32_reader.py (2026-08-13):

import serial
import serial.tools.list_ports
import time
from pathlib import Path

BAUD_RATE = 115200


def find_esp32():
    for port in serial.tools.list_ports.comports():
        description = (port.description or "").lower()

        if (
            "cp210" in description
            or "silicon labs" in description
            or "ch340" in description
            or "usb serial" in description
        ):
            return port.device

    return None


def connect():
    port = find_esp32()

    if port is None:
        raise RuntimeError("ESP32 not found.")

    print(f"Connecting to {port}...")

    ser = serial.Serial(
        port,
        BAUD_RATE,
        timeout=1
    )

    time.sleep(2)

    ser.reset_input_buffer()

    print("Connected.")

    return ser


def get_file_list(ser):
    ser.reset_input_buffer()

    ser.write(b"LIST\n")
    ser.flush()

    files = []
    started = False

    start_time = time.time()

    while True:

        if time.time() - start_time > 5:
            raise TimeoutError("Timed out waiting for file list.")

        raw = ser.readline()

        if not raw:
            continue

        line = raw.decode(
            "utf-8",
            errors="ignore"
        ).strip()

        if line == "LIST_START":
            started = True
            continue

        if line == "LIST_END":
            break

        if started and line.endswith(".csv"):
            files.append(line)

    return files


def download_file(ser, filename):
    ser.reset_input_buffer()

    clean_name = filename.lstrip("/")

    print(f"\nDownloading {clean_name}...")

    ser.write(
        f"GET {filename}\n".encode("utf-8")
    )

    ser.flush()

    lines = []
    receiving = False

    start_time = time.time()

    while True:

        if time.time() - start_time > 10:
            raise TimeoutError("Download timed out.")

        raw = ser.readline()

        if not raw:
            continue

        line = raw.decode(
            "utf-8",
            errors="ignore"
        ).rstrip("\r\n")

        if line == "ERROR:FILE_NOT_FOUND":
            raise RuntimeError("File not found on ESP32.")

        if line == "FILE_START":
            receiving = True
            continue

        if line == "FILE_END":
            break

        if receiving:
            lines.append(line)

    downloads_folder = Path.home() / "Downloads"

    destination = downloads_folder / clean_name

    with open(
        destination,
        "w",
        encoding="utf-8",
        newline=""
    ) as file:

        for line in lines:
            file.write(line + "\n")

    print(f"Downloaded successfully.")
    print(f"Saved to: {destination}")


def main():
    ser = None

    try:
        ser = connect()

        files = get_file_list(ser)

        if not files:
            print("No CSV files found on ESP32.")
            return

        print("\nCSV files on ESP32:\n")

        for i, filename in enumerate(files, start=1):
            print(f"{i}. {filename.lstrip('/')}")

        print()

        while True:
            choice = input(
                "Which file would you like to download? "
            ).strip()

            try:
                choice_number = int(choice)

                if 1 <= choice_number <= len(files):
                    break

            except ValueError:
                pass

            print("Invalid selection.")

        selected_file = files[choice_number - 1]

        download_file(
            ser,
            selected_file
        )

    except Exception as e:
        print(f"Error: {e}")

    finally:
        if ser is not None and ser.is_open:
            ser.close()


if __name__ == "__main__":
    main()

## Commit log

2026-08-13 Rename Screenshot 2026-08-13 121542.png to pcb_layout.png
2026-08-13 Revise README for Portable ESP32 Time-Study System
    Updated project description, added engineering outcomes, key accomplishments, system architecture, hardware details, software information, installation instructions, typical use, engineering discipli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
2026-08-15 Update README with prototype photos and demo video
